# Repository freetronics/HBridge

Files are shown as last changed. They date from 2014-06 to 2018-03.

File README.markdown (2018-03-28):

Freetronics H-Bridge Shield
===========================
Copyright 2014 Freetronics Pty Ltd  
Freetronics site:  www.freetronics.com  
Freetronics email: info@freetronics.com  

FIXME

Features:

 * Overlay guide where you need it (both top and bottom)
 * FIXME

You can view more at our product page at:

  http://www.freetronics.com/hbridge

The "docs" folder within this repository includes a handy copy of the
schematic in PDF format, images of the pcb, and our Getting Started
guide that ships with each board.

INSTALLATION
------------
The design is saved as an EAGLE project. EAGLE PCB design software is
available from www.cadsoftusa.com free for non-commercial use. To use
this project download it and place the directory containing these files
into the "eagle" directory on your computer. Then open EAGLE and
navigate to Projects -> eagle -> HBridge.

DISTRIBUTION
------------
The specific terms of distribution of this project are governed by the
license referenced below.

LICENSE
-------
Licensed under the TAPR Open Hardware License (www.tapr.org/OHL).
The "license" folder within this repository also contains a copy of
this license in plain text format.

CREDITS
-------
The H-Bridge Shield was designed by Luke Weston (reindeerflotilla@gmail.com)

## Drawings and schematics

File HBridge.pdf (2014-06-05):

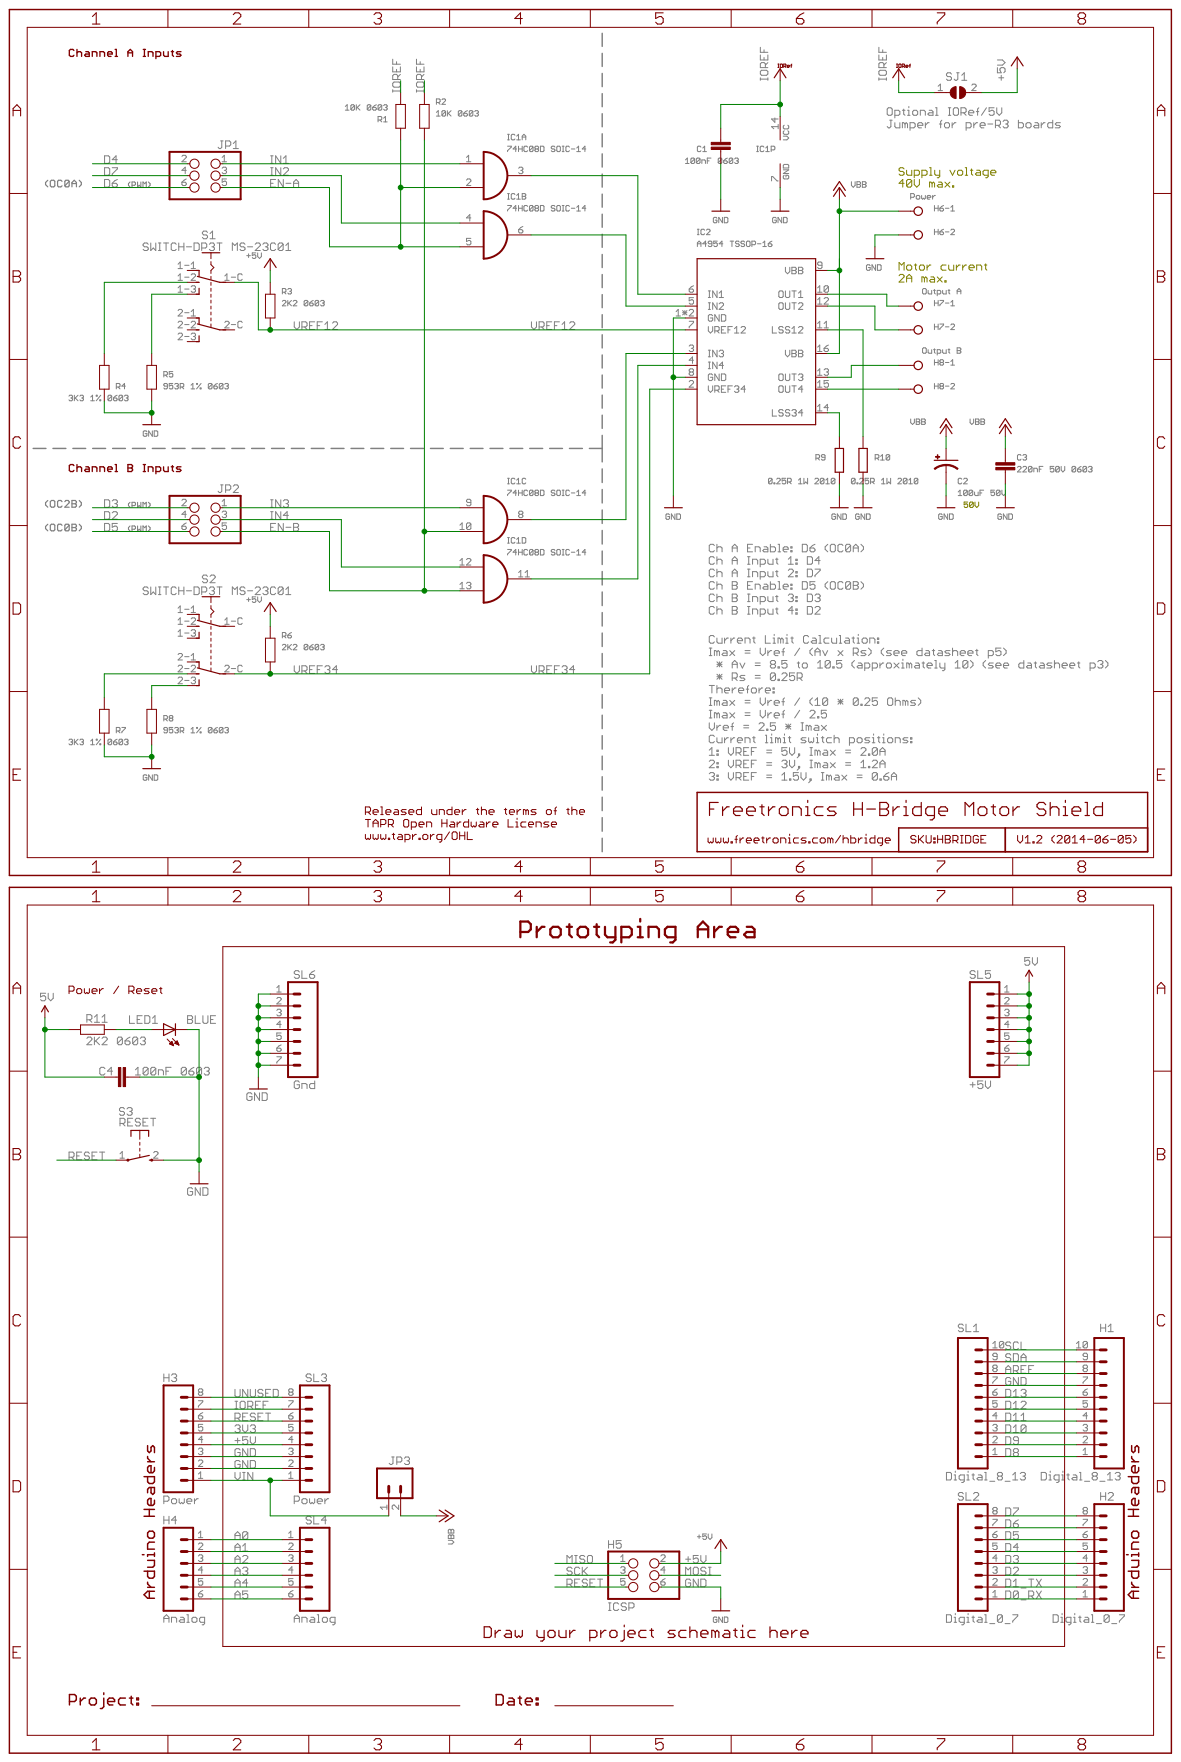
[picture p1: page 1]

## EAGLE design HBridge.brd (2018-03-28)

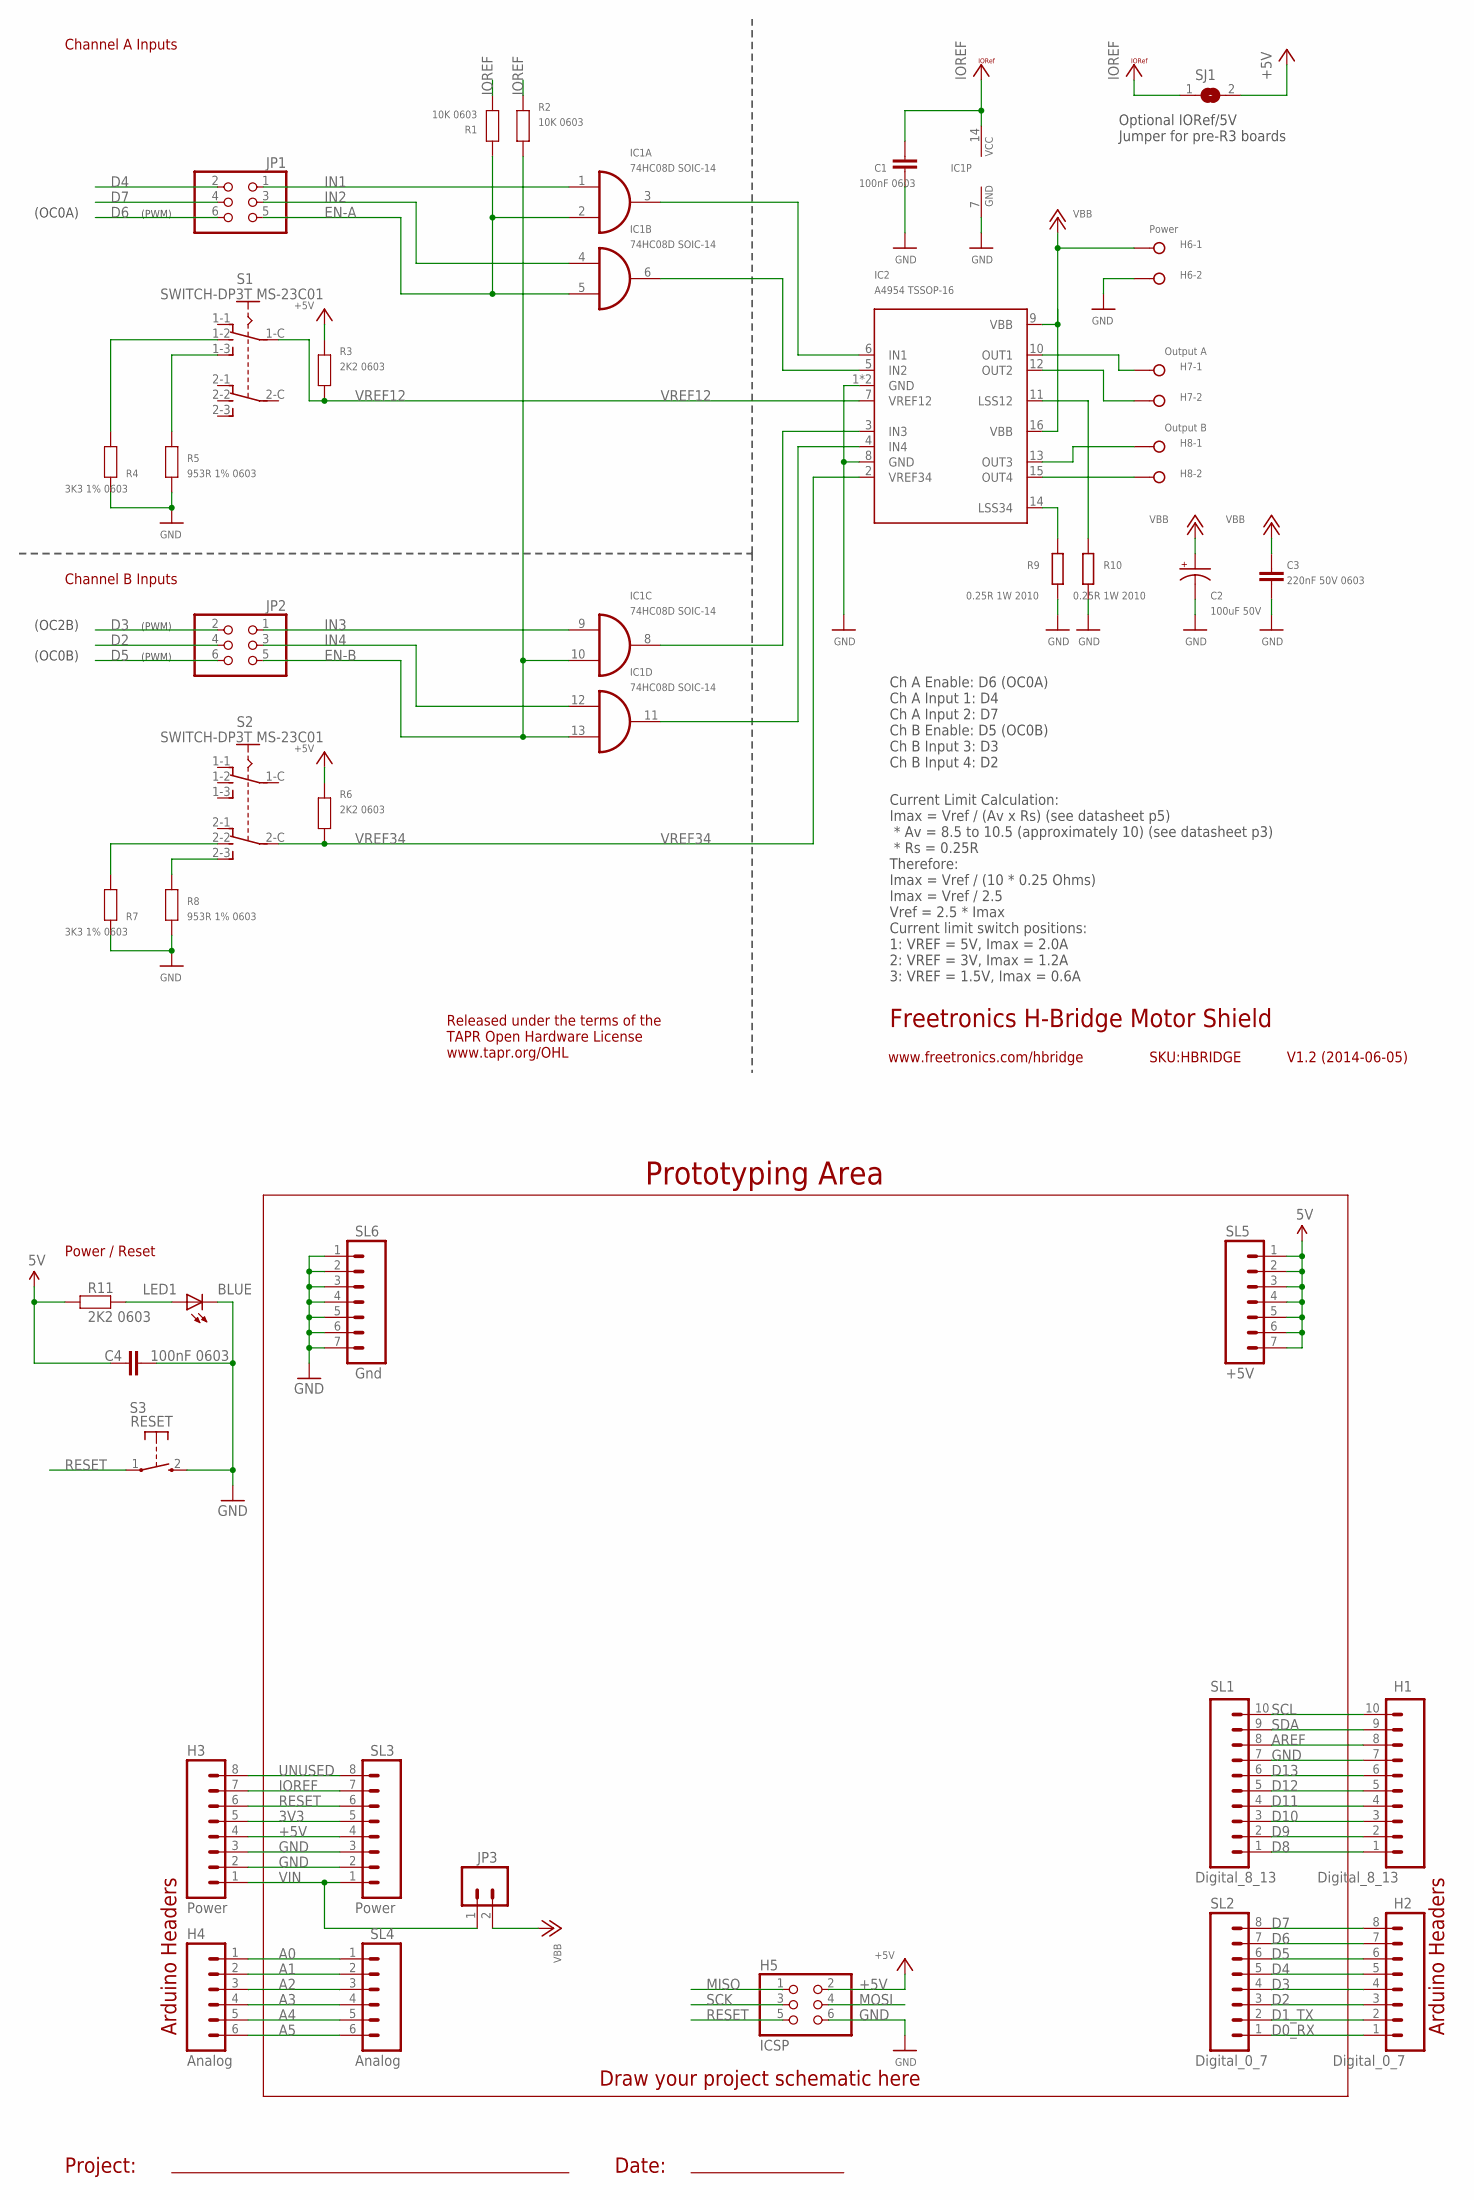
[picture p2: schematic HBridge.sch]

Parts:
C1, C4: 100nF 0603; 0603
C2: 100uF 50V; PANASONIC_E
C3: 220nF 50V 0603; 0603
H1: Digital_8_13; 1X10
H2: Digital_0_7; 1X08
H3: Power; 1X08
H4: Analog; 1X06
H5: ICSP; 2X03
H6: Power; W237-132
H7: Output A; W237-132
H8: Output B; W237-132
IC1: 74HC08D SOIC-14; SO14
IC2: A4954 TSSOP-16; TSSOP16-LP
JP1, JP2: PINHD-2X3; 2X03
JP3: M02PTH; 1X02
LED1: BLUE; LED-0603
R1, R2: 10K 0603; 0603
R3, R6, R11: 2K2 0603; 0603
R4, R7: 3K3 1% 0603; 0603
R5, R8: 953R 1% 0603; 0603
R9, R10: 0.25R 1W 2010; R2010
S1, S2: SWITCH-DP3T MS-23C01; MS-23C01
S3: RESET; TACTILE_SWITCH_SMD_2PIN_TINY
SJ1: SJ
SL1: Digital_8_13; 1X10
SL2: Digital_0_7; 1X08
SL3: Power; 1X08
SL4: Analog; 1X06
SL5: +5V; 1X07
SL6: Gnd; 1X07

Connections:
3V3: H3.5, SL3.5
+5V: C4.1, H3.4, H5.2, R3.1, R6.1, R11.1, SJ1.2, SL3.4, SL5.1, SL5.2, SL5.3, SL5.4, SL5.5, SL5.6, SL5.7
A0: H4.1, SL4.1
A1: H4.2, SL4.2
A2: H4.3, SL4.3
A3: H4.4, SL4.4
A4: H4.5, SL4.5
A5: H4.6, SL4.6
AREF: H1.8, SL1.8
D0_RX: H2.1, SL2.1
D1_TX: H2.2, SL2.2
D2: H2.3, JP2.4, SL2.3
D3: H2.4, JP2.2, SL2.4
D4: H2.5, JP1.2, SL2.5
D5: H2.6, JP2.6, SL2.6
D6: H2.7, JP1.6, SL2.7
D7: H2.8, JP1.4, SL2.8
D8: H1.1, SL1.1
D9: H1.2, SL1.2
D10: H1.3, SL1.3
D11: H1.4, SL1.4
D12: H1.5, SL1.5
D13: H1.6, SL1.6
EN-A: IC1.2 (I1), IC1.5 (I1), JP1.5, R1.2
EN-B: IC1.10 (I1), IC1.13 (I1), JP2.5, R2.1
GND: C1.2, C2.-, C3.2, C4.2, H1.7, H3.2, H3.3, H5.6, H6.2, IC1.7 (GND), IC2.1 (GND), IC2.8 (GND), IC2.EXP (GND), LED1.C, R4.2, R5.2, R7.2, R8.2, R9.1, R10.1, S3.2 (S), SL1.7, SL3.2, SL3.3, SL6.1, SL6.2, SL6.3, SL6.4, SL6.5, SL6.6, SL6.7
IN1: IC1.1 (I0), JP1.1
IN2: IC1.4 (I0), JP1.3
IN3: IC1.9 (I0), JP2.1
IN4: IC1.12 (I0), JP2.3
IOREF: C1.1, H3.7, IC1.14 (VCC), R1.1, R2.2, SJ1.1, SL3.7
MISO: H5.1
MOSI: H5.4
unnamed: R8.1, S2.2-3
unnamed: IC1.11 (O), IC2.4 (IN4)
unnamed: IC1.8 (O), IC2.3 (IN3)
unnamed: IC1.6 (O), IC2.5 (IN2)
unnamed: IC1.3 (O), IC2.6 (IN1)
unnamed: H7.1, IC2.10 (OUT1)
unnamed: H7.2, IC2.12 (OUT2)
unnamed: H8.1, IC2.13 (OUT3)
unnamed: H8.2, IC2.15 (OUT4)
unnamed: IC2.14 (LSS34), R9.2
unnamed: IC2.11 (LSS12), R10.2
unnamed: R4.1, S1.1-2
unnamed: R5.1, S1.1-3
unnamed: LED1.A, R11.2
unnamed: R7.1, S2.2-2
RESET: H3.6, H5.5, S3.1, SL3.6
SCK: H5.3
SCL: H1.10, SL1.10
SDA: H1.9, SL1.9
UNUSED: H3.8, SL3.8
VBB: C2.+, C3.1, H6.1, IC2.9 (VBB), IC2.16 (VBB), JP3.2
VIN: H3.1, JP3.1, SL3.1
VREF12: IC2.7 (VREF12), R3.2, S1.1-C
VREF34: IC2.2 (VREF34), R6.2, S2.2-C

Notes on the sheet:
Prototyping Area
Power / Reset
Arduino Headers
Draw your project schematic here
Project:
Date:
Freetronics H-Bridge Motor Shield
V1.2 (2014-06-05)
www.freetronics.com/hbridge
SKU:HBRIDGE
Current Limit Calculation: Imax = Vref / (Av x Rs) (see datasheet p5) * Av = 8.5 to 10.5 (approximately 10) (see datasheet p3) * Rs = 0.25R Therefore: Imax = Vref / (10 * 0.25 Ohms) Imax = Vref / 2.5 Vref = 2.5 * Imax Current limit switch positions: 1: VREF = 5V, Imax = 2.0A 2: VREF = 3V, Imax = 1.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
Channel A Inputs
Channel B Inputs
(PWM)
(OC0B)
Released under the terms of the TAPR Open Hardware License www.tapr.org/OHL
(OC2B)
(OC0A)
Ch A Enable: D6 (OC0A) Ch A Input 1: D4 Ch A Input 2: D7 Ch B Enable: D5 (OC0B) Ch B Input 3: D3 Ch B Input 4: D2
Optional IORef/5V Jumper for pre-R3 boards

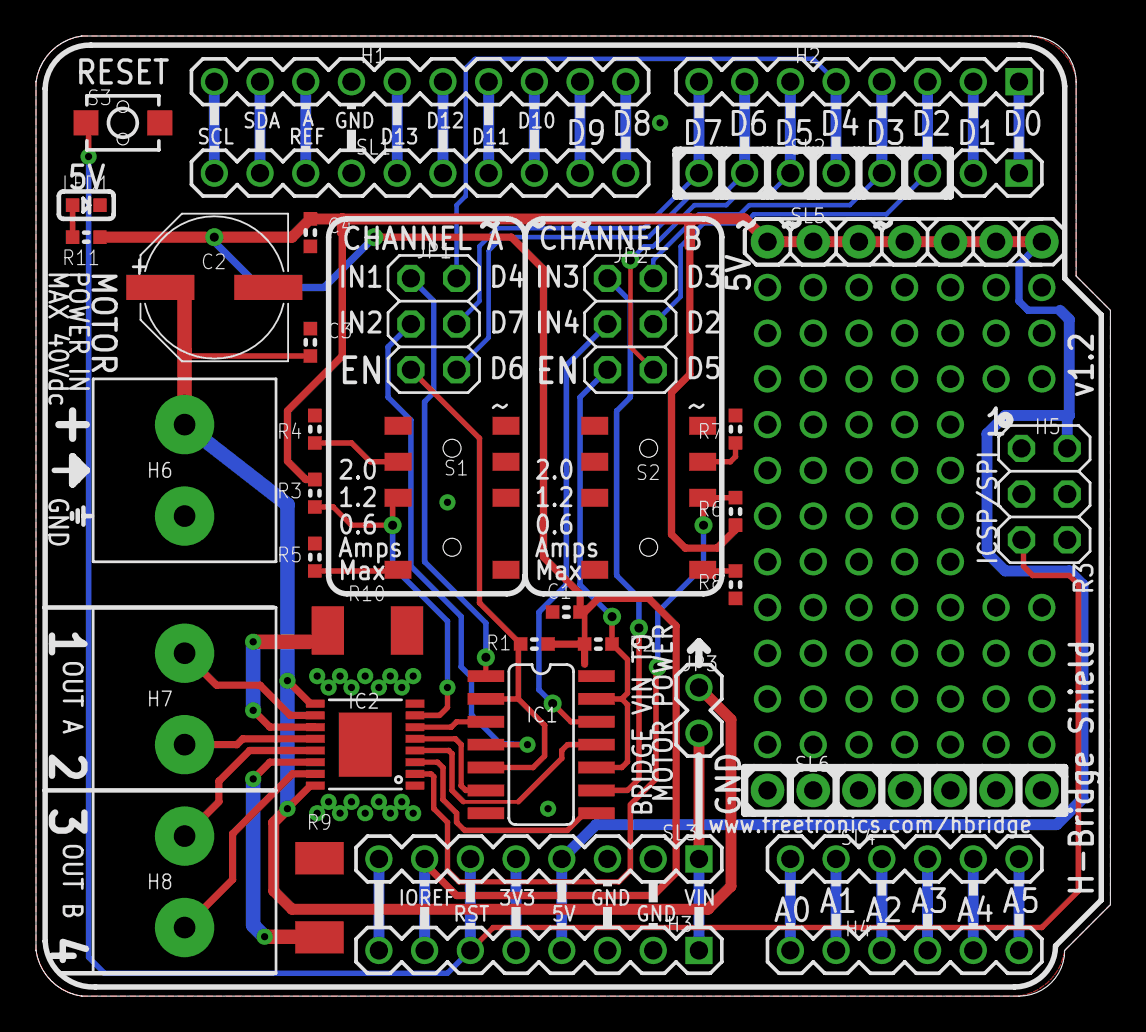
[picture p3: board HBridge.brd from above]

Board: 2 copper layers, 59.7 x 53.3 mm, 39 parts (1 on the bottom side), 54 nets.

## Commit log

2012-11-04 Added ICSP header for R3
    [HBridge.brd, HBridge.sch]
2012-11-04 Replaced reset button with smaller 2-pin version
    [HBridge.brd, HBridge.sch]
2012-11-04 Removed obsolete gerbers
    [HBridge.GBL, HBridge.GBS, HBridge.GTL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]
2012-11-04 Improved position of pwr LED
    [HBridge.brd]
2012-11-05 Made track widths consistent; renamed parts; relocated designators, improved silkscreen
    [HBridge.brd, HBridge.sch]
2012-11-05 Ground polygon tweak
    [HBridge.brd]
2013-03-31 Restructured schematic and board for switchable current limit
    [HBridge.brd, HBridge.sch]
2013-04-03 Changed input pins; rerouted; ERC and DRC
    [HBridge.brd, HBridge.sch]
2013-07-18 Annotation updates for release
    [HBridge.brd, HBridge.sch]
2014-06-04 Add schematic PDF
2014-06-05 Version 1.2: 3.3V compatibility via the IORef pin on Arduino R3
    [HBridge.brd, HBridge.sch]
2014-06-30 Remove second version number and update first V1.2, bump Copyright date
    [HBridge.brd]

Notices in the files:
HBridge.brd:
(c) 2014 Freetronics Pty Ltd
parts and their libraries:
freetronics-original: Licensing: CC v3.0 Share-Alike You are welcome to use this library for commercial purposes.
